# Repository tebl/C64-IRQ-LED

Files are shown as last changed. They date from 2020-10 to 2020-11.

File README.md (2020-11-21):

# C64 IRQ LED
I was looking for something similar to the Amigas Bifrost-module, but for the Commodore 64 since that is the machine that is closest to my 8-bit heart. Looking around I found an [article](https://www.nightfallcrew.com/04/03/2011/commodore-64-irq-bicolor-led/) with a snippet from an old dutch magazine (complete copy [here](https://github.com/tebl/C64-IRQ-LED/blob/main/gallery/resetknop.jpg)), it uses a dual-colour LED that changes colour depending on the status of the IRQ-line. What that means is that when the Commodore 64 is accessing I/O devices such as system ROMs, cartridge or disk systems the power LED will change to green - and back to red again, when finished. Exciting stuff!

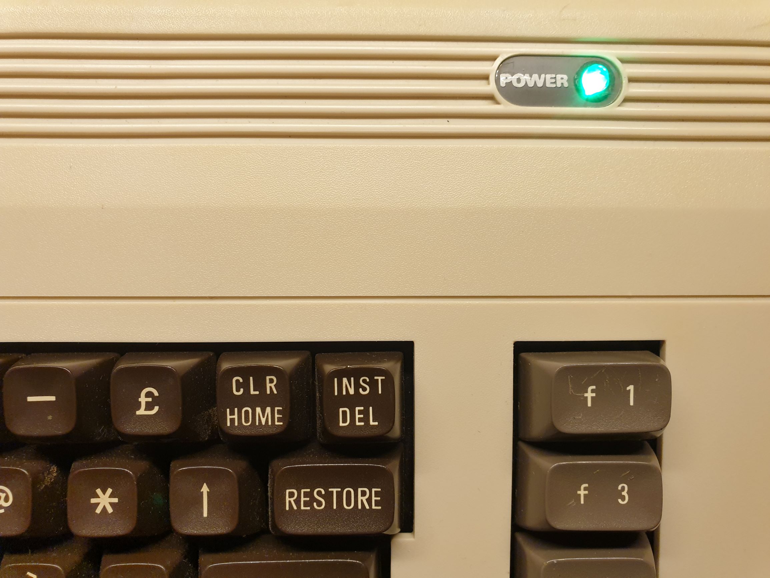
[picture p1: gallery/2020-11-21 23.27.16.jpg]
It's green!


## Build and install
Most of the construction is straight forward, just follow the BOM below as well as the notices where you need to make a few decisions. Do I need or want to bother with a switch? Does my RGB LED work?

Connector J2 is there so you can use an SPDT-switch to disable the LED module, ensuring it will always stay red. According to discussions I've seen, it might get irritating when using things such as GEOS because *everything* uses an IRQ, so if you do - consider wiring up one to these pins. If you do not need it, solder a piece of wire across pins 1-2.

You need to get a common cathode (*CC*) LED with more than one colour, ideally a dual colour one like in the original article. Personally I just cut off the blue pin on a *CC* RGB, then used that though the effect is better with frosted LEDs instead of the clear ones. **Don't** solder it into place until you've test-fitted it for length in place inside your C64 case, solder everything else instead.

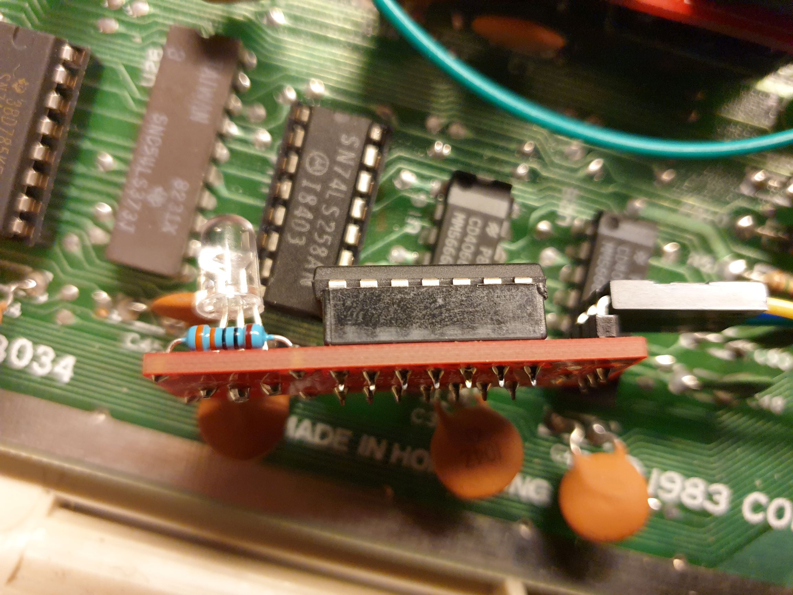
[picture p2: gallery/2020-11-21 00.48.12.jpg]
All together now

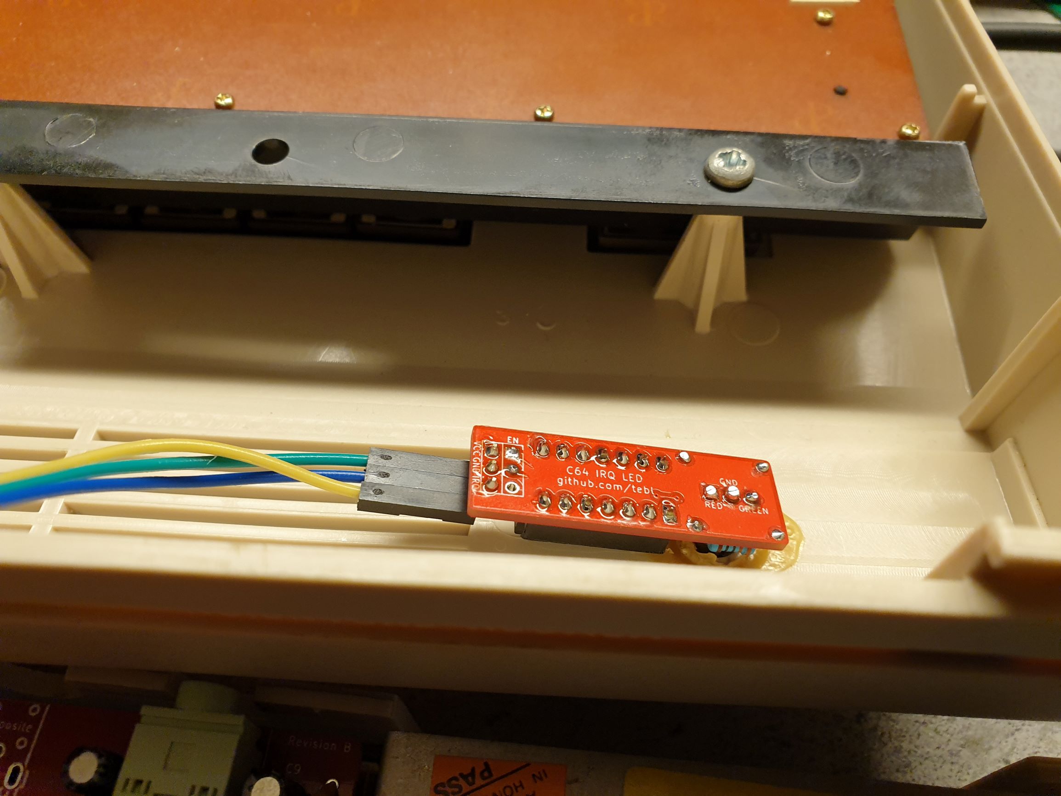
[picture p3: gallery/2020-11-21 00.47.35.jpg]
Fitting


Next step is to buy another breadbin-style Commodore 64, because you probably deserve one! Then, remove old power LED and save it in a drawer somewhere (or sell it on ebay as a *"rare"* spare part). Hopefully some bedroom engineer haven't glued the thing in there - in my case it was rubberized glue so that fell apart decades ago. The newer RGB LED might be a tight fit for the existing LED mount though it should fit - just apply some pressure on the front to snap it into place. Afterwards, add the module on top - it might stay on there by itself. if it doesn't you'll need to add some double-sided tape to the IC. Now you can probably solder the LED legs into place permanently - just take care not to melt your case!

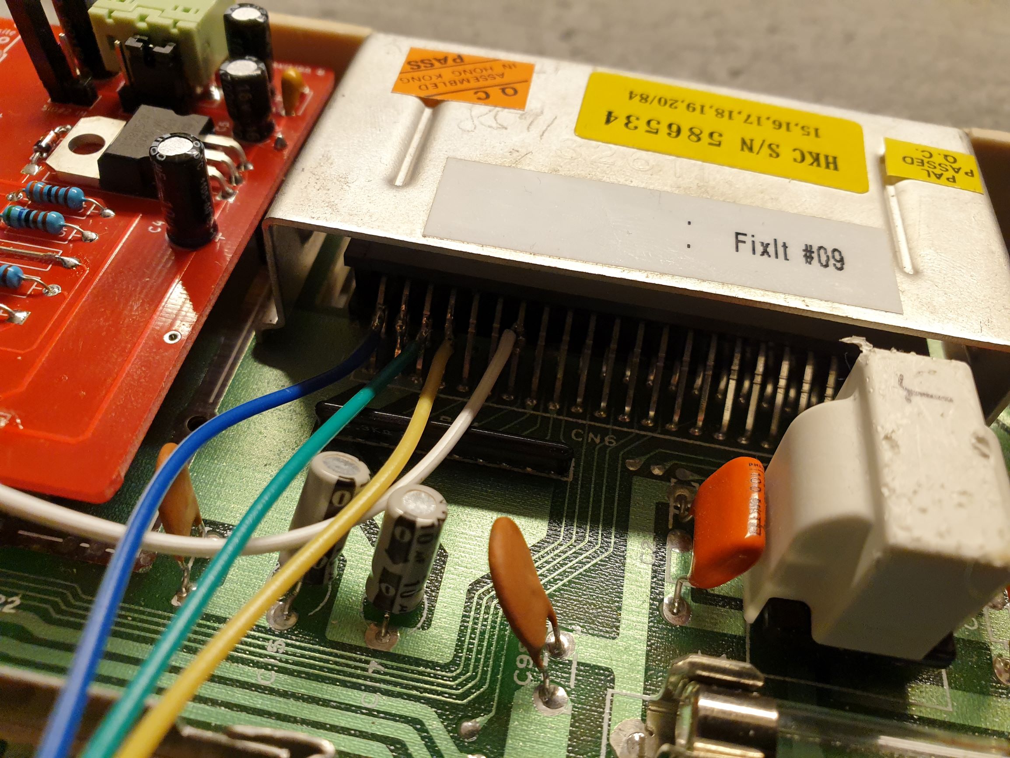
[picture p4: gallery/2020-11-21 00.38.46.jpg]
Adding wires


The last piece of the puzzle is attaching the whole thing to the C64 motherboard, you can refer to the picture above as this is where I added the three wires needed (white wire is for [Stereo SID](https://github.com/tebl/C64-Stereo-SID) board). I'm using a cut-off set of female dupont wires, the easiest is to wire them to the cartridge port and matching the female part of it to the **markings on the board** (pin order has been changed). Looking at the cartridge port as pictured above: 
- Pin 1, the blue wire, goes to GND (J1 pin 1)
- Pin 3, the green wire, goes to VCC (J1 pin 2)
- Pin 4, the yellow wire, goes to IRQ (J1 pin 3)

Before powering up, double-check that GND and VCC is in the correct spot, swapping them around will kill the IC on the IRQ LED board. Enjoy your freqeuently green power LED!

# BOM
Most parts should be easy to get a hold of from your favourite local electronic component shop, but since I don't have access to the more serious ones I'm mostly getting my components from ebay/AliExpress (free shipping most places, but plan on waiting 3-4 weeks though).

| Reference | Item | Count |
| --- | --- | ----- |
| PCB | Fabricate using Gerber files ([order](https://www.pcbway.com/project/shareproject/Commodore_64_IRQ_LED.html))  | 1 |
| D1 * | 5mm Bi-colour LED (common cathode) | 1 |
| J1 | 3-pin right-angle header pins | 1 |
| J2 ** | Piece of wire | 1 |
| R1,R2 | 330 ohm resistor | 2 | 
| U1 | 74LS04 or 74HCT04 (DIP-14) | 1 |

*) These are 3 pin LEDs of the common cathode variety, check using diode test on a multimeter to ensure that the center pin is GND and that you know which colour goes where. Alternatively, jam a CR2032 battery between the pins. Common cathode RGB LED can be used, just cut off the blue one.

**) You can wire a 3-pin SPDT wire into these pins as a means to enable/disable the mod, solder a piece of leftover wire between pins 1-2 to enable it permanently (if you do not want a switch).

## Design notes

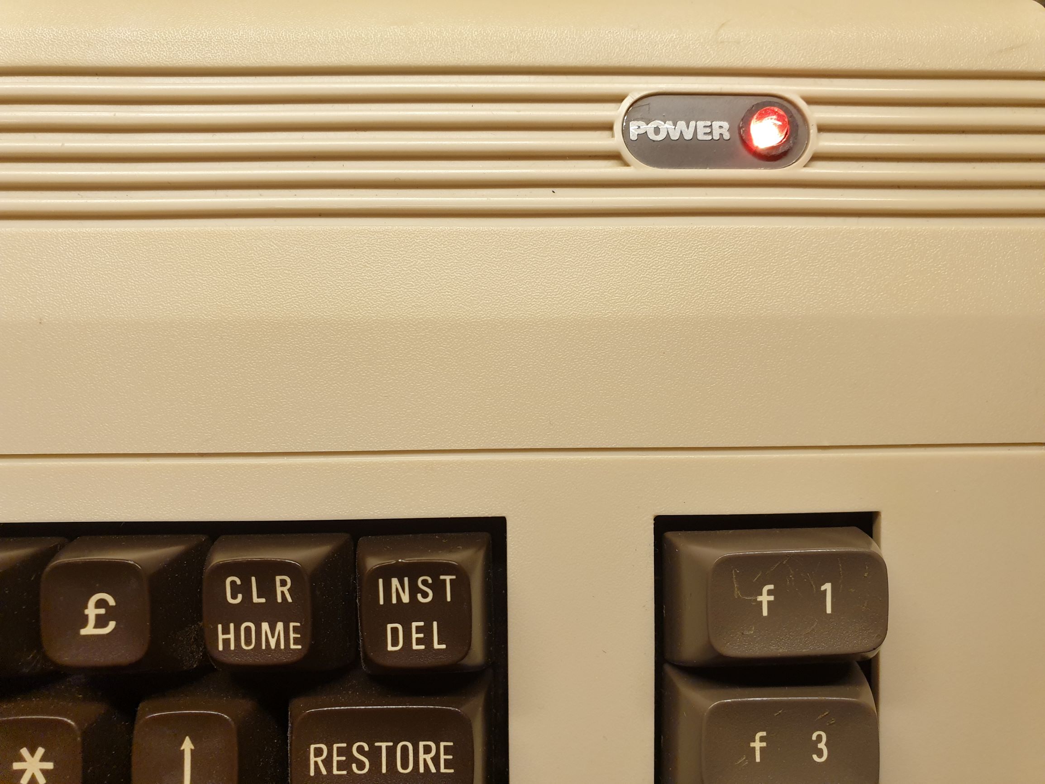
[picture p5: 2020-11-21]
gallery/2020-11-21 23.27.10.jpg

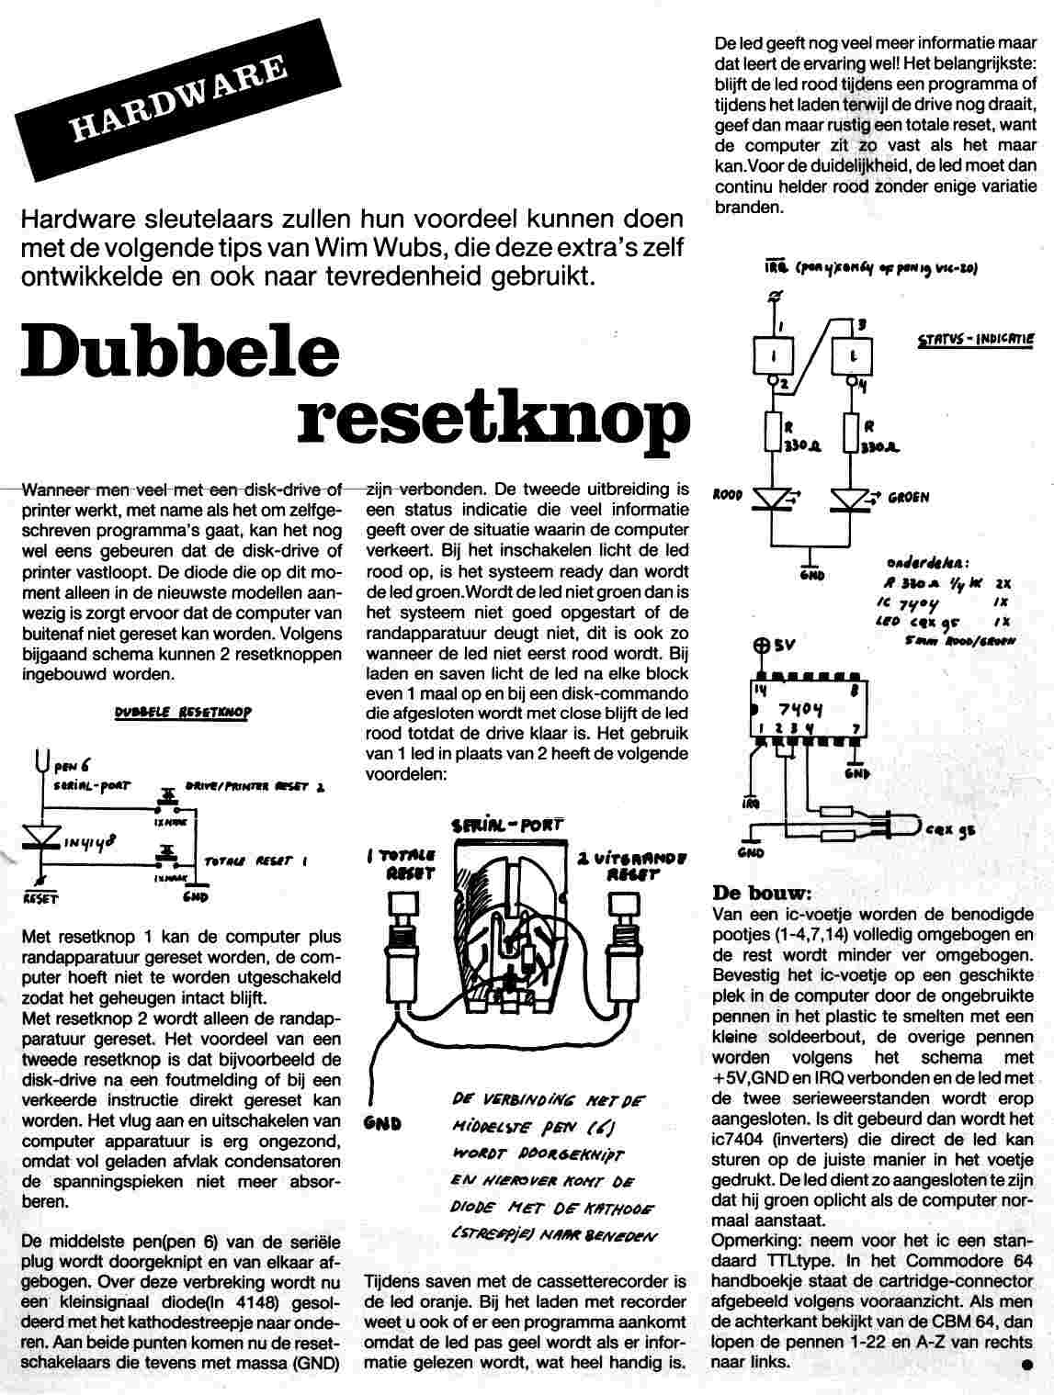
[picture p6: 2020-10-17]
gallery/resetknop.jpg

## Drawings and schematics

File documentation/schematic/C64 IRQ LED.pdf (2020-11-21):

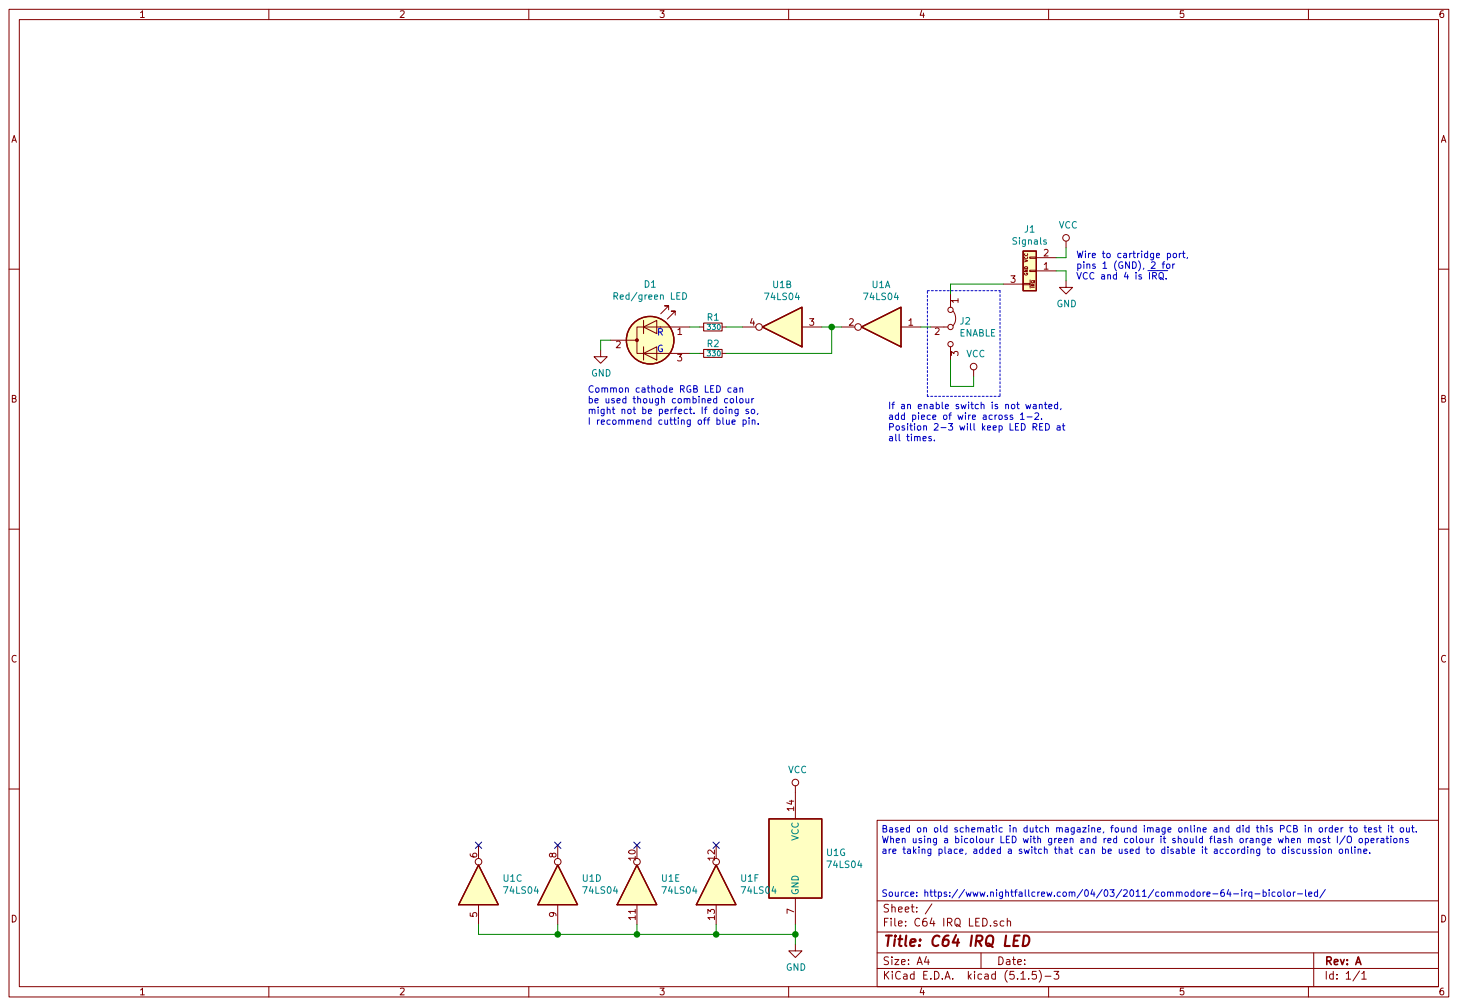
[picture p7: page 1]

J1 Signals VCC VCC 14 GND
74LS04 GND

3 J2ENABLE GND GND VCC IRQ 1

pins 1 (GND), 2 for VCC and 4 is IRQ. Source: https://www.nightfallcrew.com/04/03/2011/commodore-64-irq-bicolor-led/

Common cathode RGB LED can
be used though combined colour
might not be perfect. If doing so,
I recommend cutting off blue pin.

If an enable switch is not wanted, add piece of wire across 1-2.

Based on old schematic in dutch magazine, found image online and did this PCB in order to test it out.
When using a bicolour LED with green and red colour it should flash orange when most I/O operations
are taking place, added a switch that can be used to disable it according to discussion online.

File: C64 IRQ LED.sch Sheet: /
Id: 1/1 Title: C64 IRQ LED

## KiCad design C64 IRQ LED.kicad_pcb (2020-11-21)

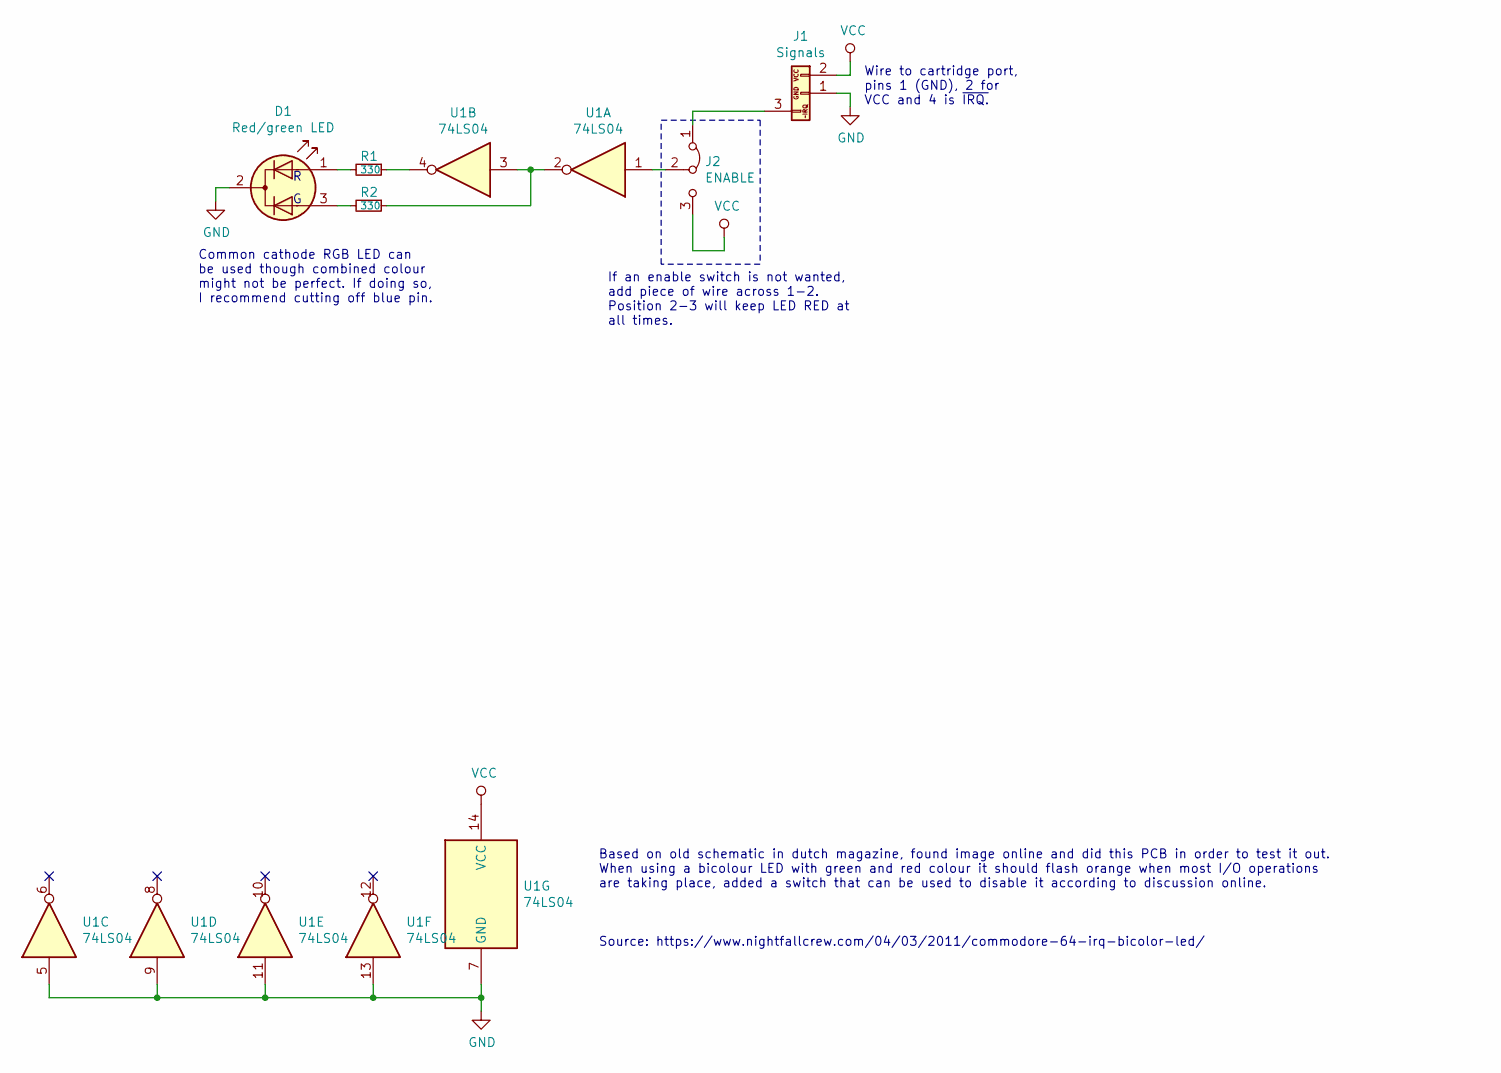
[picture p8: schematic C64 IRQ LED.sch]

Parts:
D1: Red/green LED; LED_D5.0mm-3
J1: Signals; Pin_Header_Angled_1x03_Pitch2.54mm
J2: ENABLE; Pin_Header_Straight_1x03_Pitch2.54mm
R1, R2: 330; R_Axial_DIN0207_L6.3mm_D2.5mm_P10.16mm_Horizontal
U1: 74LS04; DIP-14_W7.62mm_LongPads

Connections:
GND: D1.2 (K), J1.1 (GND), U1.5, U1.7 (GND), U1.9, U1.11, U1.13
unnamed: D1.1 (A1), R1.2
unnamed: D1.3 (A2), R2.2
unnamed: J1.3, J2.1 (A)
unnamed: J2.2 (C), U1.1
unnamed: R1.1, U1.4
unnamed: R2.1, U1.2, U1.3
VCC: J1.2 (VCC), J2.3 (B), U1.14 (VCC)

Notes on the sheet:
Based on old schematic in dutch magazine, found image online and did this PCB in order to test it out. When using a bicolour LED with green and red colour it should flash orange when most I/O operations are taking place, added a switch that can be used to disable it according to discussion online.
Source: https://www.nightfallcrew.com/04/03/2011/commodore-64-irq-bicolor-led/
Wire to cartridge port, pins 1 (GND), 2 for VCC and 4 is ~IRQ.
If an enable switch is not wanted, add piece of wire across 1-2. Position 2-3 will keep LED RED at all times.
Common cathode RGB LED can be used though combined colour might not be perfect. If doing so, I recommend cutting off blue pin.

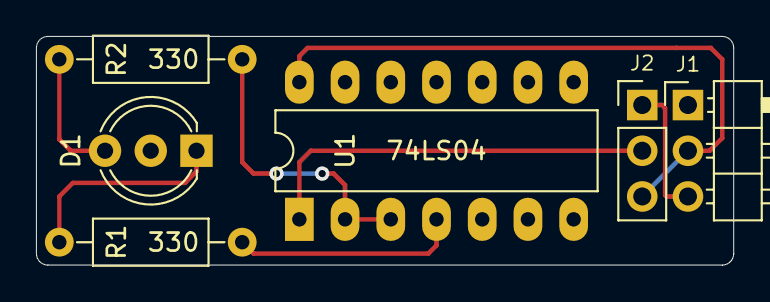
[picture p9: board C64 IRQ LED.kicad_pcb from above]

Board: 2 copper layers, 38.7 x 12.7 mm, 6 parts (0 on the bottom side), 8 nets.

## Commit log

2020-10-17 Basic schematic
    [C64 IRQ LED.kicad_pcb, C64 IRQ LED.sch]
2020-10-17 Gerber expor
    [C64 IRQ LED-B_Cu.gbl, C64 IRQ LED-B_Mask.gbs, C64 IRQ LED-B_Paste.gbp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]
2020-11-21 Changed pin order to match expansion port
    [C64 IRQ LED-B_Cu.gbl, C64 IRQ LED-B_Mask.gbs, C64 IRQ LED-B_Paste.gbp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]
